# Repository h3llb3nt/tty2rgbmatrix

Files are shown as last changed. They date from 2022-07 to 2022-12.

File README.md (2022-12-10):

# tty2rgbmatrix
MiSTer fpga add-on showing text, pictures or animated gifs on an RGB matrix panel powered by an ESP32

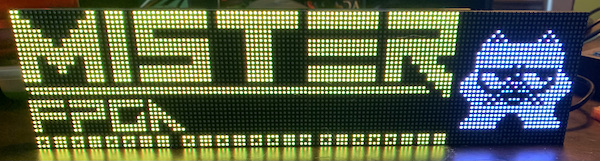
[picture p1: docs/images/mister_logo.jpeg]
mister_logo

 
this project is adapted from https://github.com/venice1200/MiSTer_tty2oled project to show mister core information on a separate display. i had an RGB matrix panel from another project lying around and figured i'd see what i could do. it has evolved from using the built in MCU flash storage to now using an external SDcard. 

# hardware
what hardware you'll need:
- this project utilizes the ESP32-HUB75-MatrixPanel-I2S-DMA library which has some requirements for which MCU you can use. mrfaptastic's github for the library states: 
	- Espressif have kept the 'ESP32' name for all their chips for brand recognition, but their new variant MCU's are different to the ESP32 this [mrfaptastic's ESP32-HUB75-MatrixPanel-I2S-DMA] library was built for.
	- The library supports the original ESP32. That being the ESP-WROOM-32 module with ESP32‑D0WDQ6 chip from 2017. This MCU has 520kB of SRAM which is much more than all the recent 'reboots' of the ESP32 such as the S2, S3, C3 etc. <b><h3>If you want to use this library, use with an original ESP32 as it has the most SRAM for DMA</b></h3>
	- Support also exists for the ESP32-S2.
	- ESP32-S3 is currently not supported (as of August 2022), but @mrfaptastic is working on this.
	- RISC-V ESP32's (like the C3) are not, and will never be supported as they do not have parallel DMA output required for this library.

- im using a Trinity EPS32 board made by Brian Lough -> https://esp32trinity.com/ which is designed specifically to interface with with the HUB75 rgb matrix panels. you can directly wire a compatible esp32 (see above warning on esp32 board that are compatible with the HUB75-MatrixPanel libaray) to HUB75 panels but you'll need to figure out the pinout, etc. and your milage may vary (YMMV). the trinity board is just the easiest way to do it in my opinion.

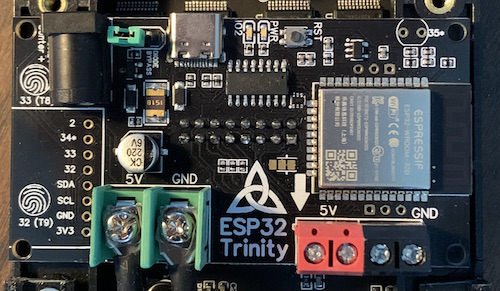
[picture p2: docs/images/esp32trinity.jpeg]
esp32 trinity board


- a HUB75 compatible RGB matrix or matrices. im using (2) 64x32 rgb panels from aliexpress -> https://www.aliexpress.com/item/3256801502846969.html

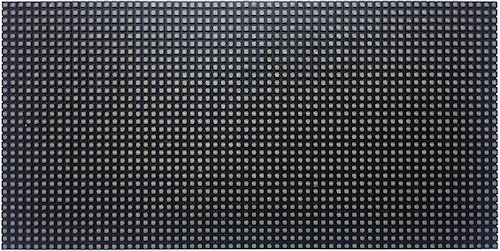
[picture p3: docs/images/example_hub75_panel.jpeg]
hub75 rgb panel


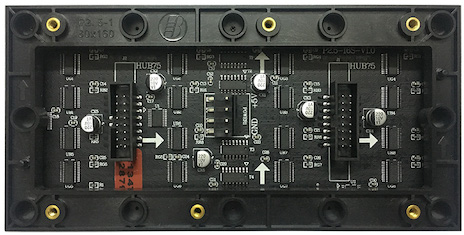
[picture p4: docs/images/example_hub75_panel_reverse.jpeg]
hub75 rgb panel reverse


- a big enough powersupply to run the MCU and RGB panels, usb power alone is NOT enough to run these panels. you MUST have an external powersupply

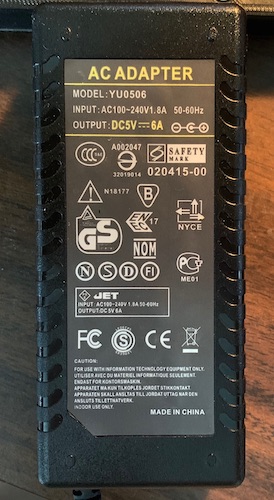
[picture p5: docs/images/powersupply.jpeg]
power supply powerbrick


- an sdcard reader module (or at the very least a modified micro to standard sdcard adapter) and an sdcard (2 gig should be MORE than enough) for storing the image files. this attaches to the trinity board using the available pins near the barrel jack power input. see the sketch file for pinout details. 

sdcard adapter sdcard

- optional: an enclosure depending on where you want your tty2rgbmatrix to go. i have included some fusion 3d files and STL files for a desktop enclosure i have created (specificly sized for the panels, MCU and sdcard module I am using!) for your use if you wish. the desktop case also includes a gap for an optional sheet or piece of LED diffusing acrlyic. you can get these from TAP plastics or other places online. size the sheet to your needs.

# software
what software you'll need:
- arduino IDE or equivalent. the animated gif library is arduino compatible only at this point. i investigated doing it circuit python but didn't get too far.
- associated libraries:
	- ESP32 HUB75 MatrixPanel I2S DMA library by mrfaptastic -> https://github.com/mrfaptastic/ESP32-HUB75-MatrixPanel-I2S-DMA
	- AnimatedGIF library by Larry Bank -> https://github.com/bitbank2/AnimatedGIF
- venice, the creator of tty2oled that started this whole thing, has created a simplified version called tty2x that simplifies what it sends from the MiSTer (as far as the active core) to the MCU. this needs to be setup on your MiSTer -> https://github.com/venice1200/MiSTer_tty2x

# software setup
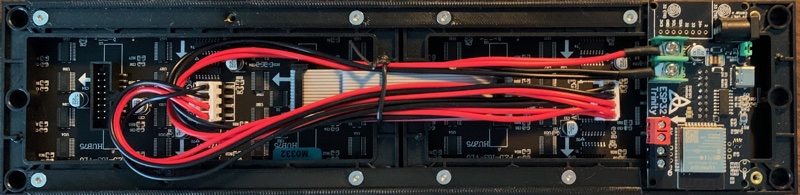
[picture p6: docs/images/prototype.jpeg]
prototype setup prototype


- (i'm working on a full installation guide from zero to hero but its taking some time, the basics are below)
- setup arduino IDE (including adding ESP32 support if you are using an ESP32 based microcontroller) and the libraries mentioned above
- the main version of tty2rgbmatrix has moved to using an sdcard, rather than the built in MCU spiffs, for storage as it ran out of space very quickly. the following instructions on uploading gifs directly to the MCU spiffs storage are no longer necessary if you are using an sdcard. 
  ~~current version of the arduino sketch looks for image files on the microcontroller's built-in storage. this requires using SPIFFS and manually uploading the images via an ESP32 Sketch Data Upload Tool in the Arduino IDE:~~
	- ~~https://github.com/me-no-dev/arduino-esp32fs-plugin~~
	- ~~This tool will upload the contents of the data/ directory in the sketch folder onto the ESP32 itself~~
- flash your ESP32 with the tty2rgbmatrix_sd.ino
- follow venice's instructions (https://github.com/venice1200/MiSTer_tty2x) on setting up tty2x on your MiSTer. these scripts run on the MiSTer linux environment and output via usb/serial to the tty2rgbmatrix MCU what core is currently running. 

# Work In Progress
items i'm still working on:
- ADD MORE GIFS OF ARCADE CORES - this is happening slowly, pulling from other sources as well. more to come...
- add font library so that text that displays for cores that do not have images created are shown in a nicer way, perhaps scroll from right to left
- ~~modify code to use an interrupt so that marquee changes happen faster. currently the code has to wait for the gif cycle to finish before it will recognize that the image should change and for longer gifs that is not ideal~~
- esp32 usually only comes with 4MB flash and a portion of that is used for code storage. current images are already filling up available space so i need to either
	- a) COMPLETED ~~add optional SDcard adapter to ESP32 board so microcontroller can access images/gifs externally rather than using storage on the microcontroller itself~~ or 
	- b) pull images directly from MiSTer like tty2oled does
- change how image files are chosen based on the core name read from the MiSTer. new sketch assumes a consistent directory structure and gif naming convention which allows for a simpler lookup routine to check for an animated gif for the core, a static version if no animated file was found, or to just display text if no image exists at all. the folder structure has been published on a separate github repo at https://github.com/h3llb3nt/marquee_gifs which is maintained by kconger, venice1200 and myself to help keep the projects consistent.

# Future Options (aka not any time soon)
- resize images/gifs that are not 128x32 'on the fly'
- add 4 more panels to make 192x64 a possibility

# Demo
https://youtu.be/un_bDXi2HBI

# Thank You!
- i want to thank all the members of the misterfpga.org forum who have helped and encouraged me to keep this project going; especially venice, reallarry, elluigi, moondandy, kconger, and everyone else on the forum 
- i also want to thanks brian lough for giving me the bug with his tetris clock for using rgb matrix panels and for designing the trinity esp32 board
- mrfaptastic for the matrix panel arduino library
- larry bank for the animated gif library
- adafruit for years of inspiration for various electronics projects
- sorg and all of the core developers on the MiSTer project
- Lu from LusRetroSource and Bob from RetroRGB for blowing this up on twitter and youtube
- and finally my wife, my daughter, and my friend theyellowdevil for (humoring me by) ooohing and ahhhing at all my flashy lights

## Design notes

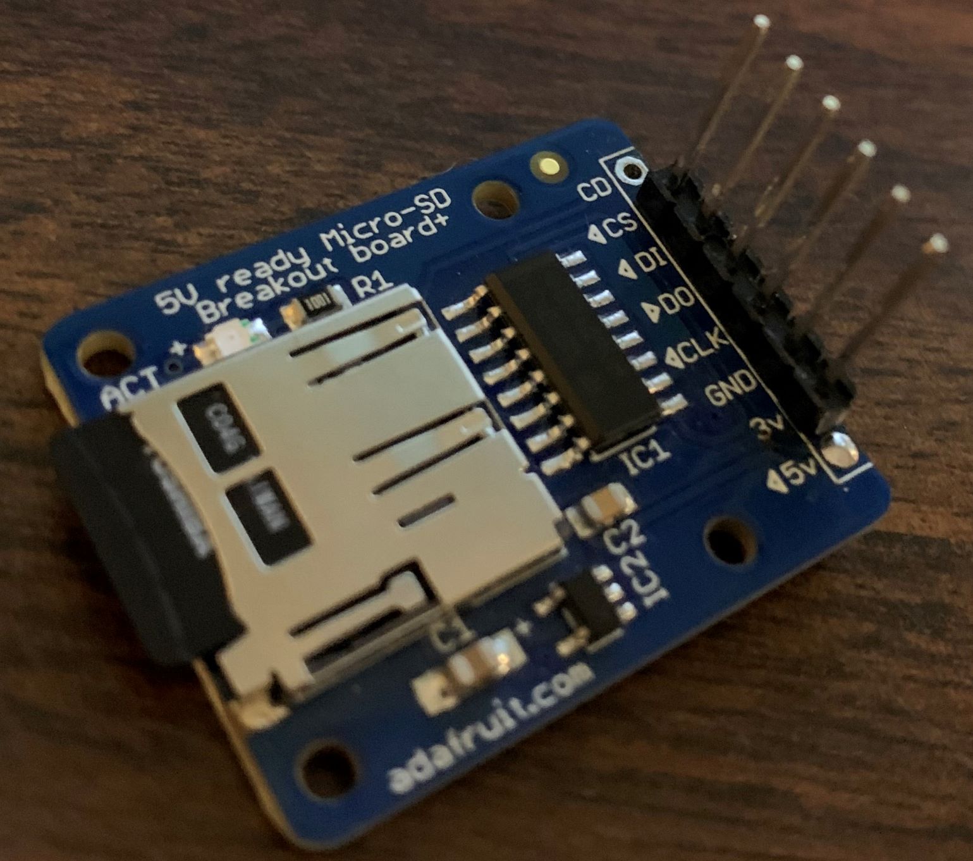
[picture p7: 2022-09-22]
docs/images/sdcard_long_pins_sm.jpeg

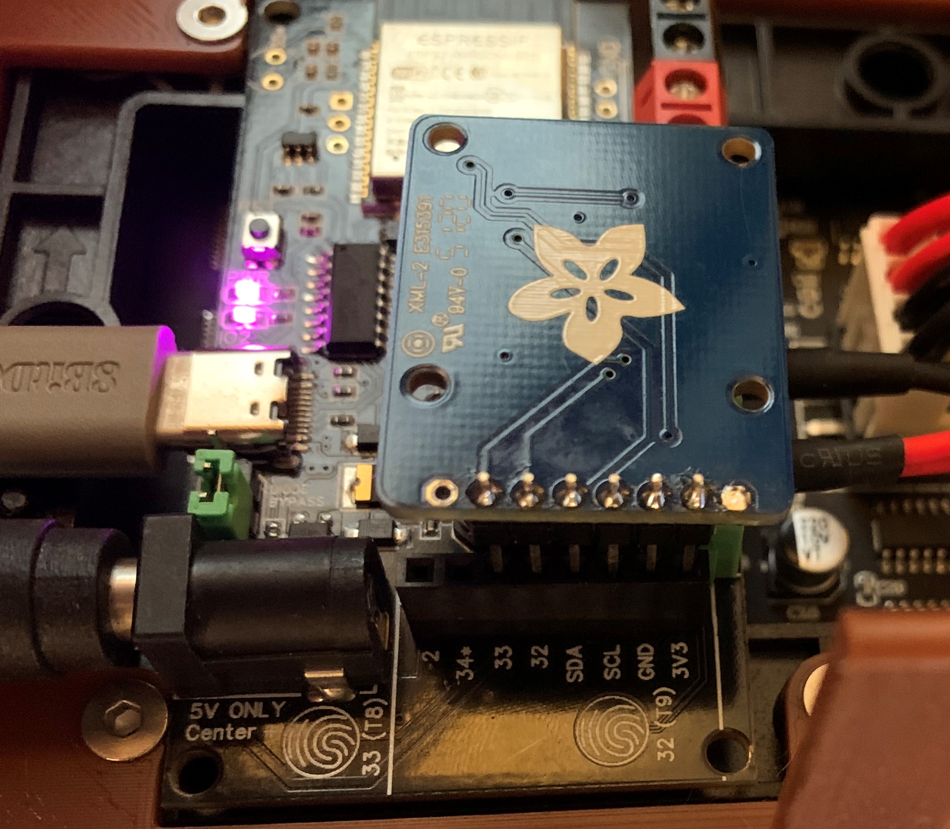
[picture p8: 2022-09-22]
docs/images/sdcard_view_top_1.jpeg

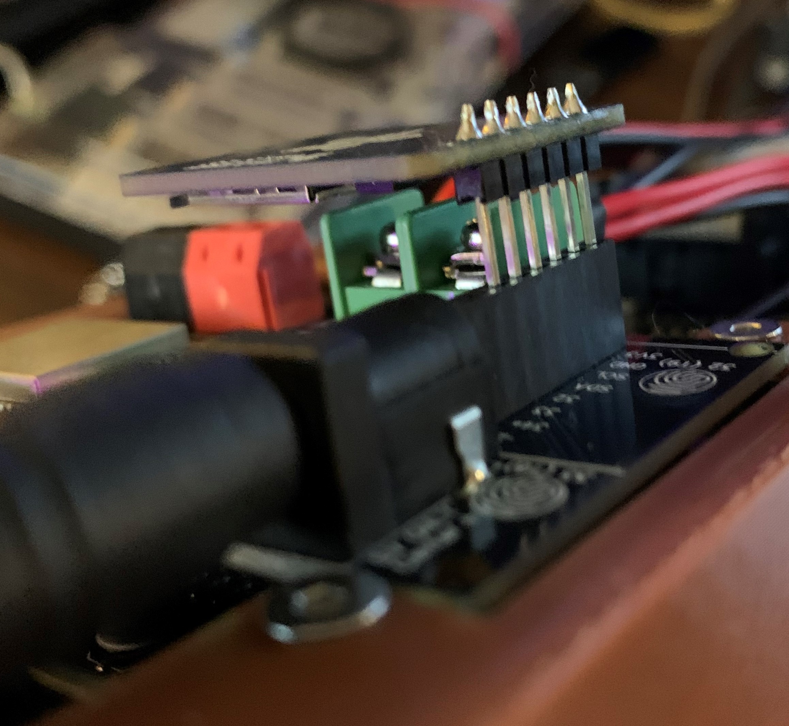
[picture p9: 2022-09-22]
docs/images/sdcard_view_side_1.jpeg

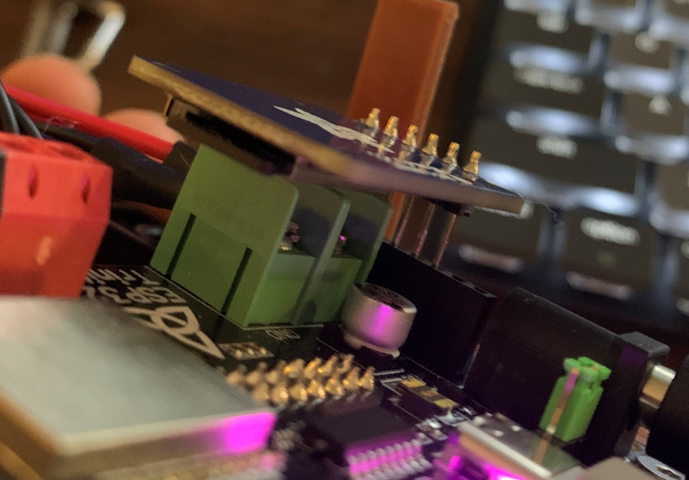
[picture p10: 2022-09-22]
docs/images/sdcard_view_side_2.jpeg

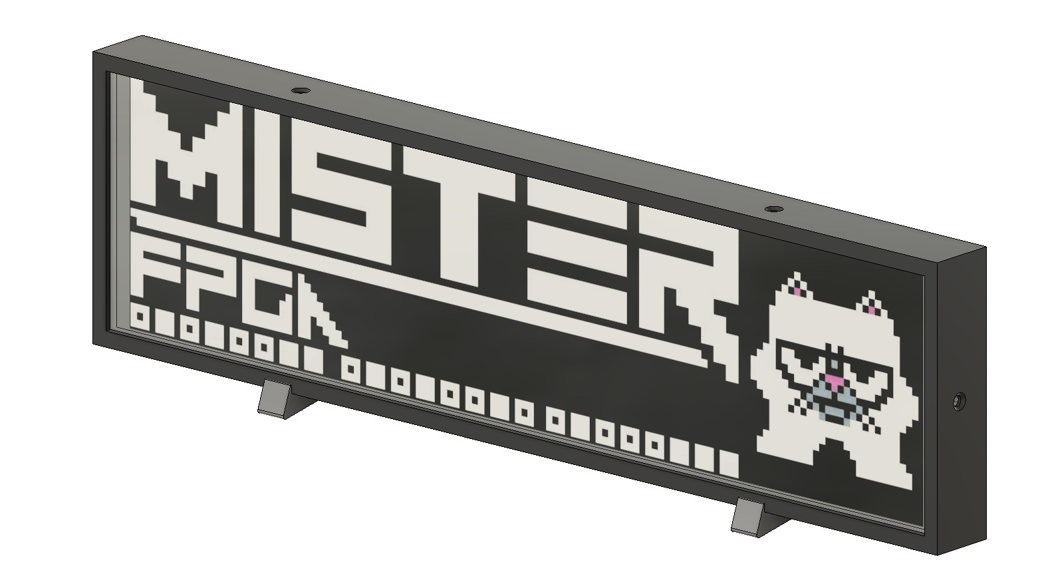
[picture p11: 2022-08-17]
desktop_frame/enclosure-front-with-panel.jpg

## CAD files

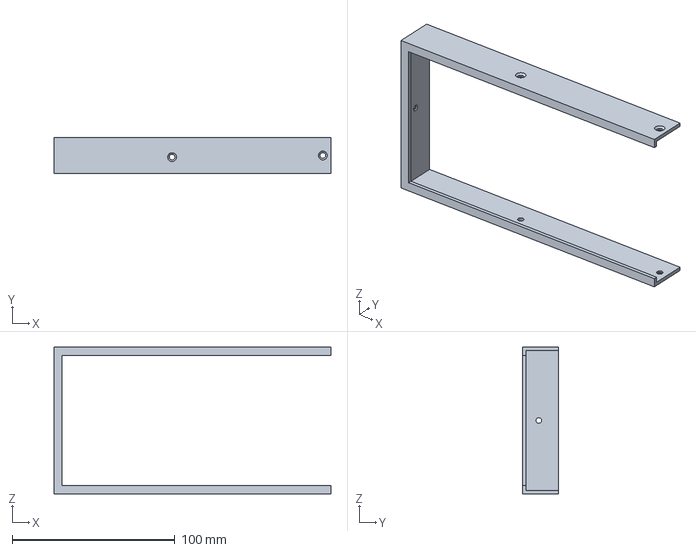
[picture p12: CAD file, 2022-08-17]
desktop_frame/STL-3MF/outer frame A.3mf
170.0 x 22.0 x 90.0 mm

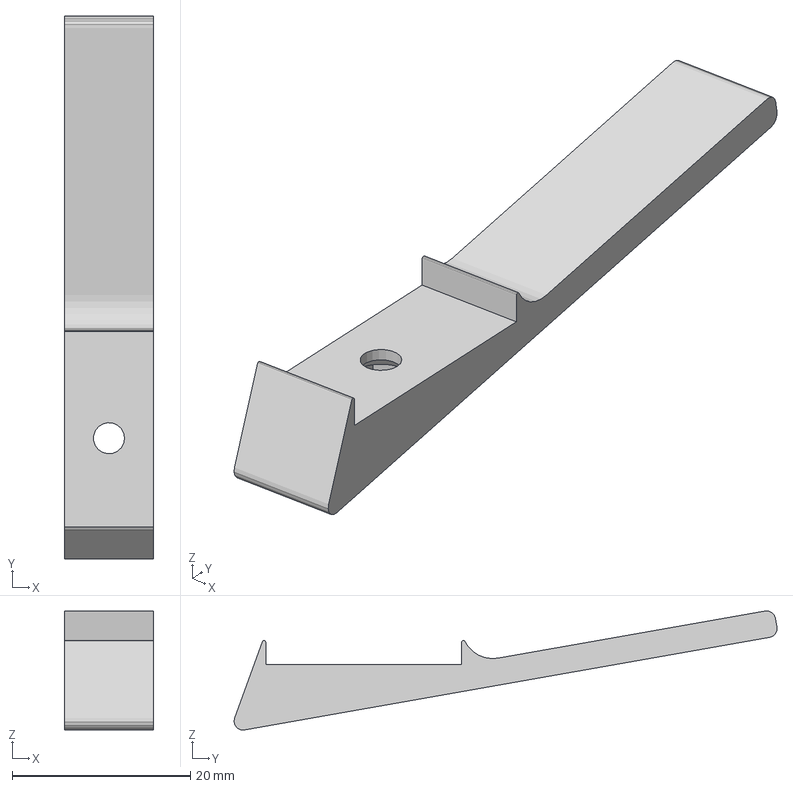
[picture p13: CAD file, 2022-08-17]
desktop_frame/STL-3MF/foot.3mf
10.0 x 61.0 x 13.4 mm

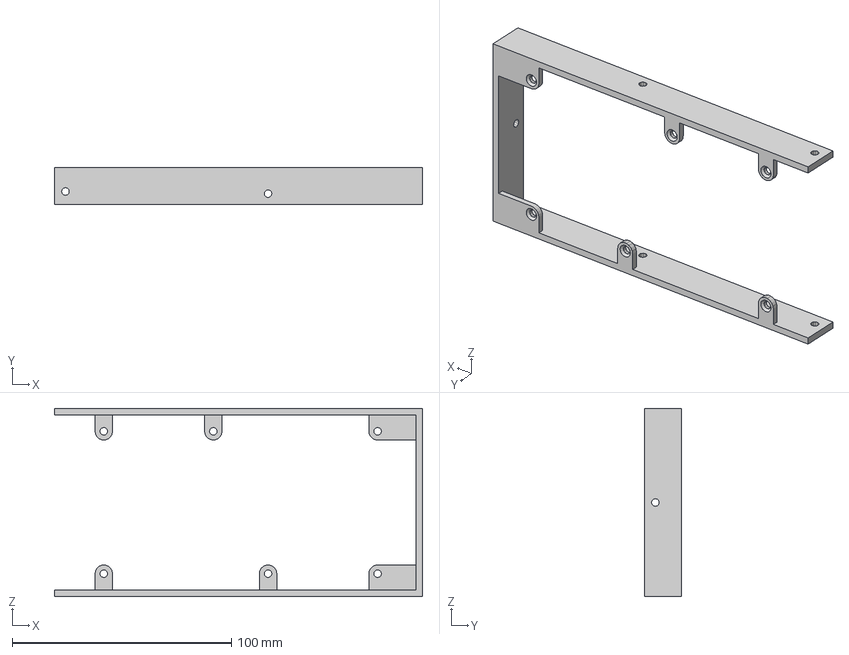
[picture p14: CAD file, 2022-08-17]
desktop_frame/STL-3MF/rear frame B.3mf
168.0 x 17.0 x 86.0 mm

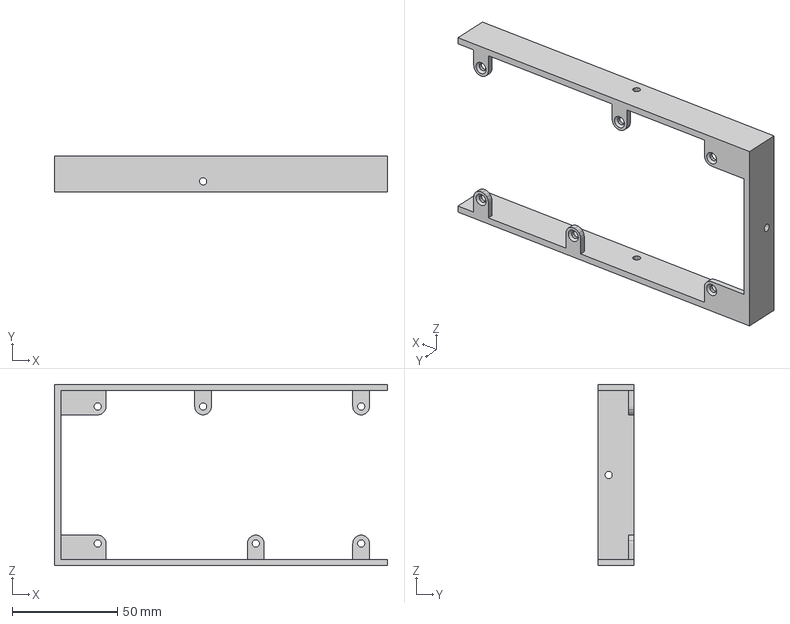
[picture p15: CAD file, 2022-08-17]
desktop_frame/STL-3MF/rear frame A.3mf
158.0 x 17.0 x 86.0 mm

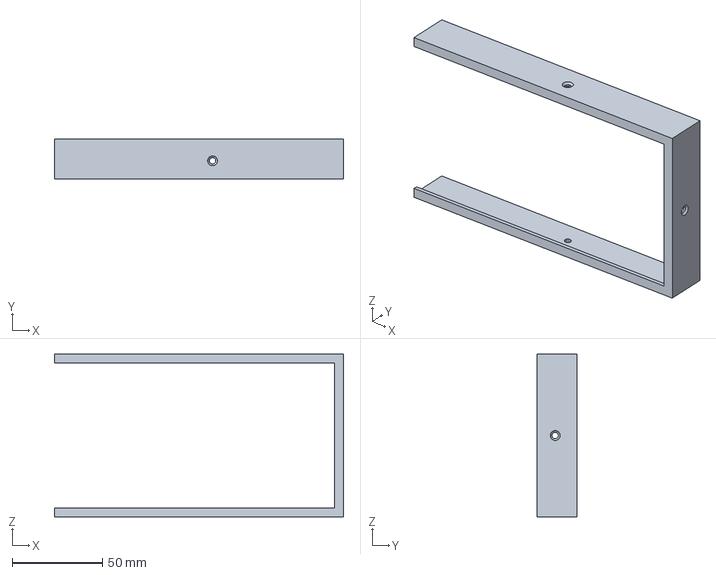
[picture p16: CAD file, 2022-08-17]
desktop_frame/STL-3MF/outer frame B.3mf
160.0 x 22.0 x 90.0 mm

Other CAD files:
desktop_frame/CAD/tty2rgbmatrix desktop case.f3d

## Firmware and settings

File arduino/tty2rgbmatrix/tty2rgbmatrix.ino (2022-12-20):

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
* You can download the latest version of this code from:
* https://github.com/h3llb3nt/tty2rgbmatrix
*///////////////////////////////////////////////////////////////

//////////////////////////////////////////////////////////////
/* change notes
 * 2022/10/07
 * modified code to not use else if table to identity core sent by mister and set appropriate gif file.
 * we use /animated and /static folders and 0-9,A-Z subfolders for images and these are named the same
 * as the core name sent by MiSTer. this allows easier lookup using a simplier check and allows for static
 * image fallback if animated does not exist or text display fallback if no image exists on card.
 * folder structure on SDcard looks like this:
 * SDCARDROOT
 * │── animated
 * │   ├── 0
 * │   ├── 1
 * │   │   └── 1944.gif
 * │   ├── 2
 * │   ├ ...
 * │   ├── A
 * │   ├ ...
 * │   └── Z
 * └── static
 *     ├── 0
 *     ├── 1
 *     │   └── 1944.gif
 *     ├── 2
 *     ├ ...
 *     ├── A
 *     ├ ...
 *     └── Z
*/
/* tty2rgbmatrix sdcard edition 2022/09/18
 * loads gif files from an sdcard and play them on an rgb matrix based on serial input from MiSTer fpga
 * those code is know to work with arduino IDE 1.8.19 with the ESP32 package version 2.0.4 installed */
//////////////////////////////////////////////////////////////

// versions of the libraries used are commented below
// use other versions at your own peril
#include <ESP32-HUB75-MatrixPanel-I2S-DMA.h>  //v2.0.7 by mrfaptastic verifed to work
#include <AnimatedGIF.h>                      //v1.4.7 by larry bank verifed to work

#define FILESYSTEM SD
//#include "SD.h"                               //v1.2.4
#include <SD.h>
#include "SPI.h"

// Micro SD Card Module Pinout                // these pins below are known to work with this config on esp32 trinity boards by brian lough
//sd  to tri
//3v3 to 3v3
//gnd to gnd
//clk to 33
//do  to 32
//di  to sda
//cs  to scl

//#define HSPI_MISO 32
//#define HSPI_MOSI 21 //trinity pin labeled SDA
//#define HSPI_SCLK 33 
//#define HSPI_CS 22   //trinity pin labeled SCL

//my pin setup so my sdcard adapter (adafruit sdcard adapter) can just slot into the pin headers on the trinity board
#define HSPI_MISO 21 //trinity pin labeled SDA
#define HSPI_MOSI 32 
#define HSPI_SCLK 22 //trinity pin labeled SCL
#define HSPI_CS 33   

SPIClass *spi = NULL;

// ----------------- RGB MATRIX CONFIG ----------------- 
// more panel setup is found in the void setup() function!

const int panelResX = 64;        // Number of pixels wide of each INDIVIDUAL panel module.
const int panelResY = 32;        // Number of pixels tall of each INDIVIDUAL panel module.
const int panels_in_X_chain = 2; // Total number of panels in X
const int panels_in_Y_chain = 1; // Total number of panels in Y

const int totalWidth  = panelResX * panels_in_X_chain;  //used in span function
const int totalHeight = panelResY * panels_in_Y_chain;  //used in span function

MatrixPanel_I2S_DMA *dma_display = nullptr;

uint16_t myBLACK = dma_display->color565(0, 0, 0);
uint16_t myWHITE = dma_display->color565(255, 255, 255);
uint16_t myRED = dma_display->color565(255, 0, 0);
uint16_t myGREEN = dma_display->color565(0, 255, 0);
uint16_t myBLUE = dma_display->color565(0, 0, 255);


// ----------------- STRING READ CONFIG ----------
String newCORE = "";             // Received Text, from MiSTer without "\n\r" currently (2021-01-11)
String currentCORE = "";         // Buffer String for Text change detection
char newCOREArray[30]="";        // Array of char needed for some functions, see below "newCORE.toCharArray"
String gifPath ="";
String subFolder ="";
char chosenGIF[256] = { 0 };


// ----------------- ANIMATEDGIF LIBRARY STUFF -----------
AnimatedGIF gif;
bool animated_flag;
File f;
int x_offset, y_offset;
int16_t xPos = 0, yPos = 0; // Top-left pixel coord of GIF in matrix space


// ----------------- GIF DRAW Gif Draw Functions -------------------------

// Copy a horizontal span of pixels from a source buffer to an X,Y position
// in matrix back buffer, applying horizontal clipping. Vertical clipping is
// handled in GIFDraw() below -- y can safely be assumed valid here.
void span(uint16_t *src, int16_t x, int16_t y, int16_t width) {
  if (x >= totalWidth) return;     // Span entirely off right of matrix
  int16_t x2 = x + width - 1;      // Rightmost pixel
  if (x2 < 0) return;              // Span entirely off left of matrix
  if (x < 0) {                     // Span partially off left of matrix
    width += x;                    // Decrease span width
    src -= x;                      // Increment source pointer to new start
    x = 0;                         // Leftmost pixel is first column
  }
  if (x2 >= totalWidth) {      // Span partially off right of matrix
    width -= (x2 - totalWidth + 1);
  }
  while(x <= x2) {
    dma_display->drawPixel(x++, y, *src++);
  } 
} /* void span() */

// Draw a line of image directly on the LCD
void GIFDraw(GIFDRAW *pDraw) {
  uint8_t *s;
  uint16_t *d, *usPalette, usTemp[320];
  int x, y;

  y = pDraw->iY + pDraw->y; // current line

  // Vertical clip
  int16_t screenY = yPos + y; // current row on matrix
  if ((screenY < 0) || (screenY >= totalHeight)) return;

  usPalette = pDraw->pPalette;

  s = pDraw->pPixels;
  
  // Apply the new pixels to the main image
  if (pDraw->ucHasTransparency)   // if transparency used
  {
    uint8_t *pEnd, c, ucTransparent = pDraw->ucTransparent;
    int x, iCount;
    pEnd = s + pDraw->iWidth;
    x = 0;
    iCount = 0;                   // count non-transparent pixels
    while (x < pDraw->iWidth) 
    {
      c = ucTransparent - 1;
      d = usTemp;
      while (c != ucTransparent && s < pEnd) 
      {
        c = *s++;
        if (c == ucTransparent)   // done, stop
        { 
          s--;                    // back up to treat it like transparent
        } 
        else                      // opaque
        {                 
          *d++ = usPalette[c];
          iCount++;
        }
      }                           // while looking for opaque pixels
      if (iCount)                 // any opaque pixels?
      {               
        span(usTemp, xPos + pDraw->iX + x, screenY, iCount);
        x += iCount;
        iCount = 0;
      }
      
      // no, look for a run of transparent pixels
      c = ucTransparent;
      while (c == ucTransparent && s < pEnd) 
      {
        c = *s++;
        if (c == ucTransparent)
          iCount++;
        else
          s--;
      }
      if (iCount) 
      {
        x += iCount;              // skip these
        iCount = 0;
      }
    }
  } 
  else                            //does not have transparency
  {                         
    s = pDraw->pPixels;
    // Translate the 8-bit pixels through the RGB565 palette (already byte reversed)
    for (x = 0; x < pDraw->iWidth; x++) 
      usTemp[x] = usPalette[*s++];
    span(usTemp, xPos + pDraw->iX, screenY, pDraw->iWidth);
  }
} /* GIFDraw() */

void * GIFOpenFile(const char *fname, int32_t *pSize)
{
  Serial.print("Playing gif: ");
  Serial.println(fname);
  f = FILESYSTEM.open(fname);
  if (f)
  {
    *pSize = f.size();
    return (void *)&f;
  }
  return NULL;
} /* GIFOpenFile() */

void GIFCloseFile(void *pHandle)
{
  File *f = static_cast<File *>(pHandle);
  if (f != NULL)
     f->close();
} /* GIFCloseFile() */

int32_t GIFReadFile(GIFFILE *pFile, uint8_t *pBuf, int32_t iLen)
{
    int32_t iBytesRead;
    iBytesRead = iLen;
    File *f = static_cast<File *>(pFile->fHandle);
    // Note: If you read a file all the way to the last byte, seek() stops working
    if ((pFile->iSize - pFile->iPos) < iLen)
       iBytesRead = pFile->iSize - pFile->iPos - 1; // <-- ugly work-around
    if (iBytesRead <= 0)
       return 0;
    iBytesRead = (int32_t)f->read(pBuf, iBytesRead);
    pFile->iPos = f->position();
    return iBytesRead;
} /* GIFReadFile() */

int32_t GIFSeekFile(GIFFILE *pFile, int32_t iPosition)
{ 
  int i = micros();
  File *f = static_cast<File *>(pFile->fHandle);
  f->seek(iPosition);
  pFile->iPos = (int32_t)f->position();
  i = micros() - i;
  //Serial.printf("Seek time = %d us\n", i);
  return pFile->iPos;
} /* GIFSeekFile() */

unsigned long start_tick = 0;

void ShowGIF(char *name, bool animated)
{
  start_tick = millis();
   
  if (gif.open(name, GIFOpenFile, GIFCloseFile, GIFReadFile, GIFSeekFile, GIFDraw))
  {
    x_offset = (MATRIX_WIDTH - gif.getCanvasWidth()) / 2;
    if (x_offset < 0) x_offset = 0;
    y_offset = (MATRIX_HEIGHT - gif.getCanvasHeight()) / 2;
    if (y_offset < 0) y_offset = 0;
    Serial.printf("Successfully opened GIF; Canvas size = %d x %d\n", gif.getCanvasWidth(), gif.getCanvasHeight());
    Serial.flush();
    if (animated) 
    {
      Serial.println("animated gif flag found, playing whole gif");
      while(gif.playFrame(true, NULL))
      {
        //keep on playing unless...
        if (Serial.available()) 
        {
          newCORE = Serial.readStringUntil('\n');                  // Read string from serial until NewLine "\n" (from MiSTer's echo command) is detected or timeout (1000ms) happens.
          Serial.println(newCORE);
          if (newCORE!=currentCORE) 
          {
            break;
          }
        }
      }
    }
    else 
    {
      Serial.println("static gif flag found, playing 1st frame of gif");
      while (!gif.playFrame(true, NULL))
      { // leaving this break in here incase i need it for interrupting the the current playing gif in a future rev     
        if ( (millis() - start_tick) > 60000) // play first frame of non-animated gif and wait 10 seconds
        { 
          //Serial.println("times up! breaking from play loop!");
          break;
        }
        else
        {
          //Serial.print(".");
          if (Serial.available())
          {
            newCORE = Serial.readStringUntil('\n');  // Read string from serial until NewLine "\n" (from MiSTer's echo command) is detected or timeout (1000ms) happens.
            Serial.println(newCORE);
            if (newCORE!=currentCORE)
            {
              break;
            }
          }
          gif.reset();
        }
      }
    }
    Serial.println("closing gif file");
    gif.close();
  }

} /* ShowGIF() */

void listDir(fs::FS &fs, const char * dirname, uint8_t levels) {
  Serial.printf("Listing directory: %s\n", dirname);

  File root = fs.open(dirname);
  if(!root){
        Serial.println("Failed to open directory");
        return;
    }
    if(!root.isDirectory()){
        Serial.println("Not a directory");
        return;
    }

  File file = root.openNextFile();
  while (file) {
    if (file.isDirectory()) {
      Serial.print("  DIR : ");
      Serial.println(file.name());
      if (levels) {
        listDir(fs, file.name(), levels -1);
      }
    } else {
      Serial.print("  FILE: ");
      Serial.print(file.name());
      Serial.print("  SIZE: ");
      Serial.println(file.size());
    }
    file = root.openNextFile();
  }
}

//String gifDir = "/"; // play all GIFs in this directory on the SD card
//char filePath[256] = { 0 };
//File root, gifFile;
  
void setup() {
  Serial.begin(115200);
  Serial.println();
  
  //Mount SD Card, display some info and list files in /gifs folder to serial output
  Serial.println("Micro SD Card Mounting...");

  spi = new SPIClass(HSPI);
  spi->begin(HSPI_SCLK, HSPI_MISO, HSPI_MOSI, HSPI_CS);

  SD.begin(HSPI_CS, *spi);
  delay(500);

  if (!SD.begin(HSPI_CS, *spi)) {
    Serial.println("Card Mount Failed");
    return;
  }
  
  uint8_t cardType = SD.cardType();

  if (cardType == CARD_NONE) {
    Serial.println("No SD card attached");
    return;
  }

  Serial.print("SD Card Type: ");

  if (cardType == CARD_MMC) {
    Serial.println("MMC");
  } else if(cardType == CARD_SD){
    Serial.println("SDSC");
  } else if(cardType == CARD_SDHC){
    Serial.println("SDHC");
  } else {
    Serial.println("UNKNOWN");
  }

  uint64_t cardSize = SD.cardSize() / (1024 * 1024);
  Serial.printf("SD Card Size: %lluMB\n", cardSize);
  // list files in /gifs folder to serial output
  // disabled 12/9/22 because this takes FOREVER to boot when the sdcard is populated and people think its not working
  //listDir(SD, "/", 2); 
  Serial.printf("Total space: %lluMB\n", SD.totalBytes() / (1024 * 1024));
  Serial.printf("Used space: %lluMB\n", SD.usedBytes() / (1024 * 1024));

  // initialize gif object
  gif.begin(LITTLE_ENDIAN_PIXELS);

  // start display
  HUB75_I2S_CFG mxconfig(
    panelResX,           // module width
    panelResY,           // module height
    panels_in_X_chain    // Chain length
  );

  // If you are using a 64x64 matrix you need to pass a value for the E pin
  // The trinity connects GPIO 18 to the typical pin E.
  // This can be commented out for any smaller displays (but should work fine with it)
  //mxconfig.gpio.e = 18;

  //swap green and blue for my specific rgb panels
  mxconfig.gpio.b1 = 26;
  mxconfig.gpio.b2 = 12;

  mxconfig.gpio.g1 = 27;
  mxconfig.gpio.g2 = 13;

  // May or may not be needed depending on your matrix
  // Example of what needing it looks like:
  // https://github.com/mrfaptastic/ESP32-HUB75-MatrixPanel-I2S-DMA/issues/134#issuecomment-866367216
  //mxconfig.clkphase = false;

  // Some matrix panels use different ICs for driving them and some of them have strange quirks.
  // If the display is not working right, try this.
  //mxconfig.driver = HUB75_I2S_CFG::FM6126A;

  dma_display = new MatrixPanel_I2S_DMA(mxconfig);
  dma_display->begin();
  dma_display->setBrightness8(16); //0-255
  dma_display->clearScreen();
  
  //screen startup test (watch for dead or misfiring pixels)
  dma_display->fillScreen(myBLACK);
  delay(500);
  dma_display->fillScreen(myRED);
  delay(500);
  dma_display->fillScreen(myGREEN);
  delay(500);
  dma_display->fillScreen(myBLUE);
  delay(500);
  dma_display->fillScreen(myWHITE);
  delay(500);
  dma_display->clearScreen();
  delay(500);
  
  dma_display->setCursor(0, 0);
  dma_display->println("tty2rgbmatrix 2022/10/08");
  delay(1000);

  dma_display->fillScreen(myBLACK);
  
  // setup initial core to default to menu
  currentCORE = "NULL";
  newCORE = "MENU";
} /* void setup() */


void loop() {
  
  if (Serial.available()) {
    newCORE = Serial.readStringUntil('\n');                  // Read string from serial until NewLine "\n" (from MiSTer's echo command) is detected or timeout (1000ms) happens.
    delay(10);
    Serial.printf("%s is oldcore, %s is newcore\n", String(currentCORE), String(newCORE));
  }
    
  if (newCORE!=currentCORE)           // Proceed only if Core Name changed
  {                                    
    Serial.printf("Running a check because %s is oldcore, %s is newcore\n", String(currentCORE), String(newCORE));
    //Serial.printf("setting animated flag to 1 since we assume animated");
    animated_flag = true;                                   // i assume animated gif is what you want to we default to that
    // -- First Transmission --
    if (newCORE.endsWith("QWERTZ"));  // TESTING: Process first Transmission after PowerOn/Reboot.                 
    
    // -- Menu Core --
    else if (newCORE=="MENU")         {strcpy(chosenGIF, "/animated/M/menu.gif"); }
    //else if (newCORE=="hellbent")     {strcpy(chosenGIF, "/animated/H/h3llb3nt.gif"); animated_flag=!animated_flag; }
    else if (newCORE=="error")        {strcpy(chosenGIF, "/animated/E/error.gif"); }
        
    // -- Test Commands --
    else if (newCORE=="cls")          ;//do something
    else if (newCORE=="sorg")         ;//do something
    else if (newCORE=="bye")          ;//do something

    else 
    {
      subFolder = String(newCORE[0]); //first letter of core is the subfolder to look in
      subFolder.toUpperCase();        //subfolders are capital, and numbers don't care about this function
      gifPath = String("/animated/" + subFolder + "/" + newCORE + ".gif");    //animated gif path string creation "/animated/X/x.gif"
      //Serial.print("animated gif path string is: ");Serial.println(gifPath);
  
      gifPath.toCharArray(chosenGIF,gifPath.length() +1);                     //sd.exists wants a character array, not a string...
  
      //Serial.print("char array chosenGIF is: ");Serial.println(chosenGIF);
      //Serial.printf("checking if animated image at %s exists", chosenGIF);Serial.println();
      if (SD.exists(chosenGIF))                                               //check if path for animated file is extant or not! if so great!
      {
        Serial.printf("char array chosenGIF %s exists!", chosenGIF);Serial.println();
      }
      else                                                                    //animated gif path did not return a 1, so file does not exist, see if a static image is there
      {
        //Serial.printf("%s did not exist, checking if a static image does", chosenGIF);Serial.println();
        gifPath = String("/static/" + subFolder + "/" + newCORE + ".gif");    //static gif path string creation "/static/X/x.gif"
        //Serial.print("static gif path string is: ");Serial.println(gifPath);
        
        gifPath.toCharArray(chosenGIF,gifPath.length() +1);                   //sd.exists wants a character array, not a string...
        
        //Serial.print("char array chosenGIF is: ");Serial.println(chosenGIF);
        //Serial.printf("checking if static image at %s exists", chosenGIF);Serial.println();
        if (SD.exists(chosenGIF))                                             //check if path for static file is extant or not! if so great!
        {
          //Serial.println("checked if static image exists...");
          //Serial.printf("char array chosenGIF %s exists!", chosenGIF);Serial.println();
          animated_flag = false;                                              //set static image boolean so gifdraw function knows its a single frame
        }
        else                                                                  //static gif path did not return a 1 either, so no file at all.
        {
          //Serial.println("checked if static image exists...");
          //Serial.printf("no animated or static file exists for newCORE: %s", newCORE);Serial.println();
          strcpy(chosenGIF, "no-match");                                      
          newCORE.toCharArray(newCOREArray, newCORE.length()+1);
        }
      }
    } // end newCORE!=currentCORE
  }
  currentCORE=newCORE;  // Update Buffer

  //no core change, show the current currentCORE gif
  //Serial.printf("%s is oldcore, %s is newcore, %s is chosenGIF\n", String(currentCORE), String(newCORE), chosenGIF);

  if (strcmp(chosenGIF,"no-match")) 
  {
    if (SD.exists(chosenGIF)) // show gif!
    {
      ShowGIF(chosenGIF,animated_flag);
    }
    else //gif not found
    {
      Serial.printf("IMAGE FILE %s NOT FOUND!\n", chosenGIF);
      dma_display->clearScreen();
      dma_display->setCursor(0, 0);
      dma_display->print(chosenGIF);
      dma_display->println(" not found");
      delay(3000);
    }
  } 
  else // show text on display of current gif
  {
    dma_display->clearScreen();
    dma_display->setCursor(0, 0);
    dma_display->println(newCOREArray);
    delay(3000);
  }  
} /* void loop() */

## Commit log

2022-06-29 figuring out how git works, fixing dir structure for arduino code
2022-07-30 esp32trinity board image
2022-07-30 power supply
2022-08-17 v1 of desktop frame
    [foot.3mf, outer frame A.3mf, outer frame B.3mf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]
2022-08-17 fusion360 archive of desktop frame
    [tty2rgbmatrix desktop case.f3d]
2022-08-17 images of desktop enclosure
2022-09-12 Update README.md
    added info on what esp32 MCU is compatible with the HUB75 library
2022-09-18 first release of sd_card edition
    this sketch pulls gifs files from a fat formatted sdcard that is attached to your microcontroller
2022-09-19 Update tty2rgbmatrix_sd.ino
    - modified so my sdcard adapter slots right into the available pins on the trinity board
    - added mr do trigger (how did i miss this?)

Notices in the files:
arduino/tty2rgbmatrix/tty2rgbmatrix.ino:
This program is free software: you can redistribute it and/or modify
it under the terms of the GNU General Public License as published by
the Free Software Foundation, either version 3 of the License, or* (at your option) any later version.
